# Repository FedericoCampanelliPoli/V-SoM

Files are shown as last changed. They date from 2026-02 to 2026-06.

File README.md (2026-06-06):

# V-SoM — Versatile System-on-Module for Power Electronics Debug & Control

<p align="center">
  
  &nbsp;&nbsp;
  
</p>

<p align="center">
  
  
  
  
  
</p>

<p align="center">
  <b>Develop. Deploy. Debug. Scale.</b><br/>
  A compact, production-ready embedded control module for power electronics, motor drives and custom control applications.
</p>

---

## Overview

Developing a custom power electronics controller typically requires:

- Designing dedicated control hardware from scratch
- Implementing communication interfaces and telemetry
- Integrating simulation environments with embedded targets
- Building software infrastructure before writing a single line of control code

**V-SoM eliminates this overhead.**

Built around the **STM32H755 dual-core microcontroller**, V-SoM combines high-performance real-time control, rapid prototyping workflows and integrated data acquisition into a single embeddable module — letting engineers focus on converter design and control algorithms rather than controller infrastructure.

---

## Key Features

| Feature | Specification |
|---|---|
| **MCU** | STM32H755 — Dual Core (Cortex-M7 + Cortex-M4) |
| **Control Core** | Cortex-M4 @ 240 MHz |
| **Communication Core** | Cortex-M7 |
| **PWM Outputs** | 5× HRTIM + 3× Advanced Timer complementary channels |
| **ADCs** | 3× 16-bit, up to 3.6 MSPS |
| **Analog Inputs** | 14 |
| **Ethernet** | 100 Mbps (integrated PHY + RJ45 with magnetics) |
| **Other Interfaces** | CAN, SPI, I²C |
| **GPIO** | 56 configurable pins |
| **Data Streaming** | Up to 60 channels @ 50 kSPS |
| **Form Factor** | 45 mm × 52 mm, 6-layer PCB, castellated edges |
| **Supply Voltage** | 3.3 V – 5.5 V |

---

## Architecture

V-SoM Architecture

| Core | Role |
|---|---|
| **Cortex-M7** | Ethernet communication, VScope server, variable read/write |
| **Cortex-M4** | User control algorithm, ADC sampling, PWM generation — fully dedicated |

This architecture guarantees **deterministic real-time execution** on the M4 while the M7 handles all telemetry and configuration transparently over Ethernet.

---

## VScope 2.0 — Integrated Real-Time Oscilloscope

One of the key features of V-SoM is **VScope 2.0**, an integrated virtual oscilloscope for real-time monitoring, editing and logging of variables running directly on the target.

<!-- ![VScope](images/vscope_main.png) -->

### Capabilities

| Capability | Detail |
|---|---|
| Channels | Up to **60** simultaneous |
| Sample Rate | Up to **50 kSPS** streaming |
| Live Editing | Modify variables at runtime |
| Acquisition | Oscilloscope-style triggering |
| Export | CSV |
| Post-processing | Supported |

Observable signals include measured variables, internal controller states, setpoints, duty cycles, protection thresholds and diagnostic data — without affecting real-time execution performance.

Communication runs over Ethernet, enabling **remote monitoring and debugging** with no additional instrumentation.

<!-- ![VScope Example](images/vscope_sinewave.png) -->
<!-- *Three-phase sinusoidal waveform streamed in real time to VScope.* -->

---

## Development Workflow

<!-- ![Workflow](images/workflow.png) -->

### 1 · Design

Develop and validate your controller in simulation:

- [PLECS](https://www.plexim.com/)
- [Simulink](https://www.mathworks.com/products/simulink.html) / Simscape
- Custom C

### 2 · Deploy

Generate embedded code or write firmware directly, then flash the target:

```bash
# Example: drag-and-drop via ST-Link (Cortex-M7 communication firmware)
# User control code runs on Cortex-M4 via your preferred toolchain
```

**Supported environments:**

| Toolchain | Target Core |
|---|---|
| Simulink Embedded Coder | Cortex-M4 |
| PLECS Coder | Cortex-M4 |
| STM32CubeIDE | Both |
| VS Code | Both |
| Bare-metal C | Both |

### 3 · Validate

Monitor all signals live with VScope 2.0 over Ethernet. Edit setpoints and parameters at runtime without stopping execution.

### 4 · Scale

Migrate the validated algorithm to a target production platform:

- STM32F4 / STM32G4 / STM32L4

or continue using V-SoM directly in **low and medium volume products**.

---

## Hardware

<!-- ![PCB Front & Back](images/vsom_front_back.png) -->
<!-- ![Pinout](images/vsom_pinout.png) -->

### Module

- **PCB:** 6-layer, 45 mm × 52 mm footprint
- **Connections:** Castellated edges — direct soldering onto carrier boards
- **Programmer:** STDC14 connector (ST-Link compatible, drag-and-drop firmware update)
- **Ethernet:** Integrated PHY + RJ45 with built-in magnetics

### Power Supply

- Dual low-noise LDO regulators
- Generates 3.3 V rail, up to **1 A** output
- Supply input: **3.3 V – 5.5 V**

### Galvanic Isolation

The integrated RJ45 connector includes built-in magnetics, providing galvanic isolation between the host PC, converter controller and external equipment — reducing EMI coupling and ground-loop issues in high-voltage environments.

---

## Applications

V-SoM has been designed for:

- Grid-tied inverters
- Motor drives (BLDC, PMSM, induction)
- Battery chargers and BMS
- Fuel-cell power converters
- Aerospace power systems
- High-voltage DC-DC converters
- Custom embedded control applications

---

## Default Firmware

The Cortex-M7 ships with communication firmware providing:

- **20 channels** read/write
- **20 kSPS** streaming rate
- Ethernet communication
- Full VScope 2.0 compatibility

Custom firmware can be flashed at any time via ST-Link drag-and-drop.

---

## Open Development Philosophy

V-SoM supports both **model-based design** (Simulink, PLECS) and **fully manual embedded development**. Engineers choose the environment that best fits their workflow while retaining full access to all underlying hardware resources.

No proprietary runtime. No closed ecosystem.

---

## Getting Started

> **Documentation:** [Insert link]  
> **Quick Start Guide:** [Insert link]

---

## Firewall Configuration

> [!WARNING]
> Windows Firewall may block incoming UDP packets required by VScope.

Run the following command **once** with administrator privileges:

```bash
netsh advfirewall firewall add rule name="VScope UDP 5005" dir=in action=allow protocol=UDP localport=5005
```

---

## License

[Insert License]

---

## Support

[Insert contact / issue tracker link]

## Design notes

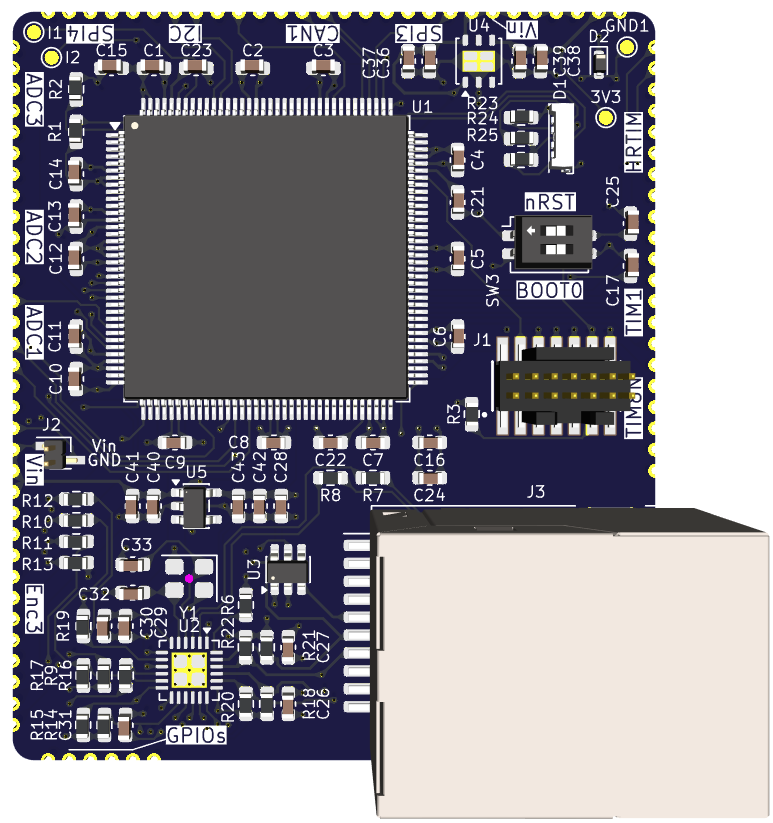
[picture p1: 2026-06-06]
Images/V-SoM_Rendering1.png

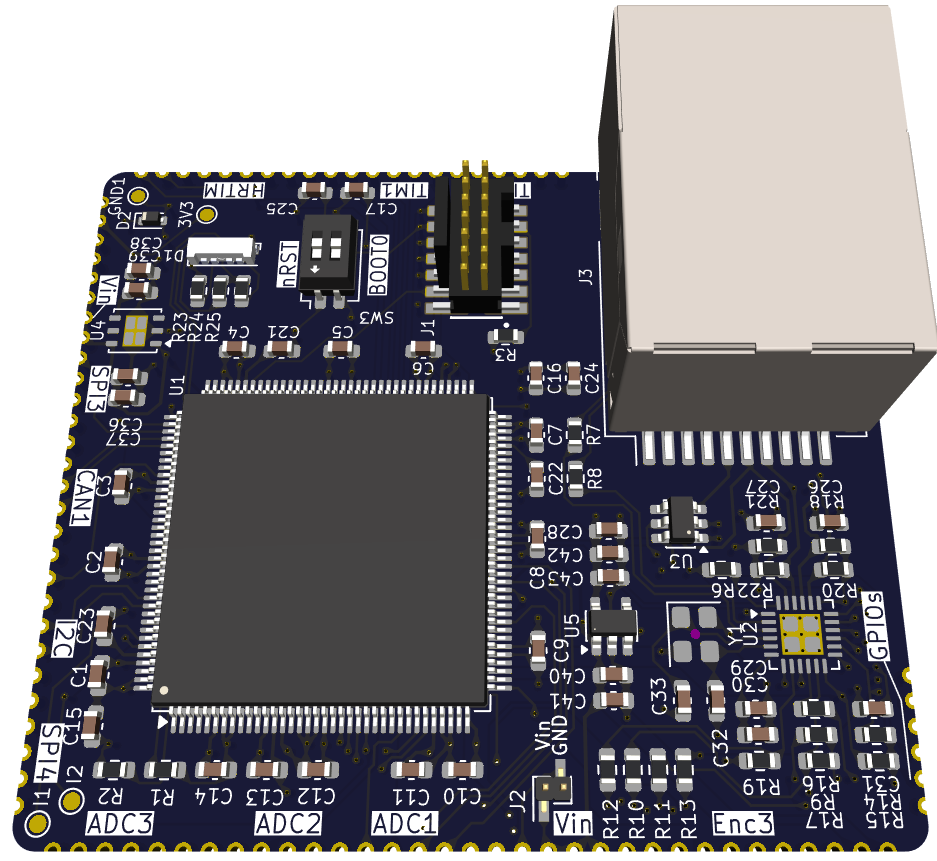
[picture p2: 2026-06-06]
Images/V-SoM_Rendering.png

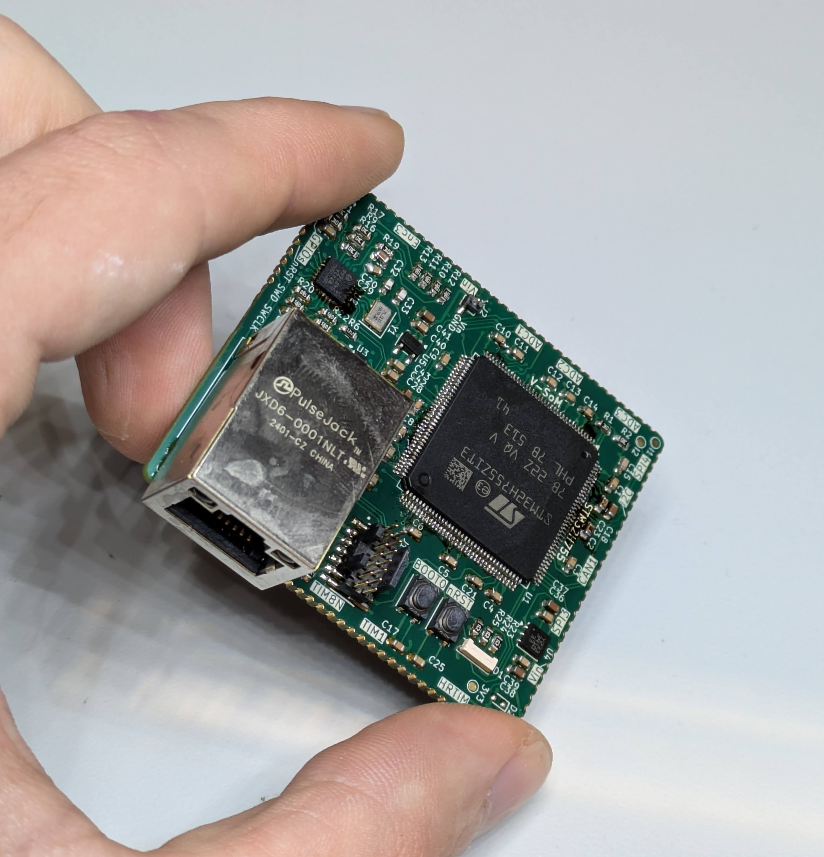
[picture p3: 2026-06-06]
Images/V-SoM_V1_Hand.jpg

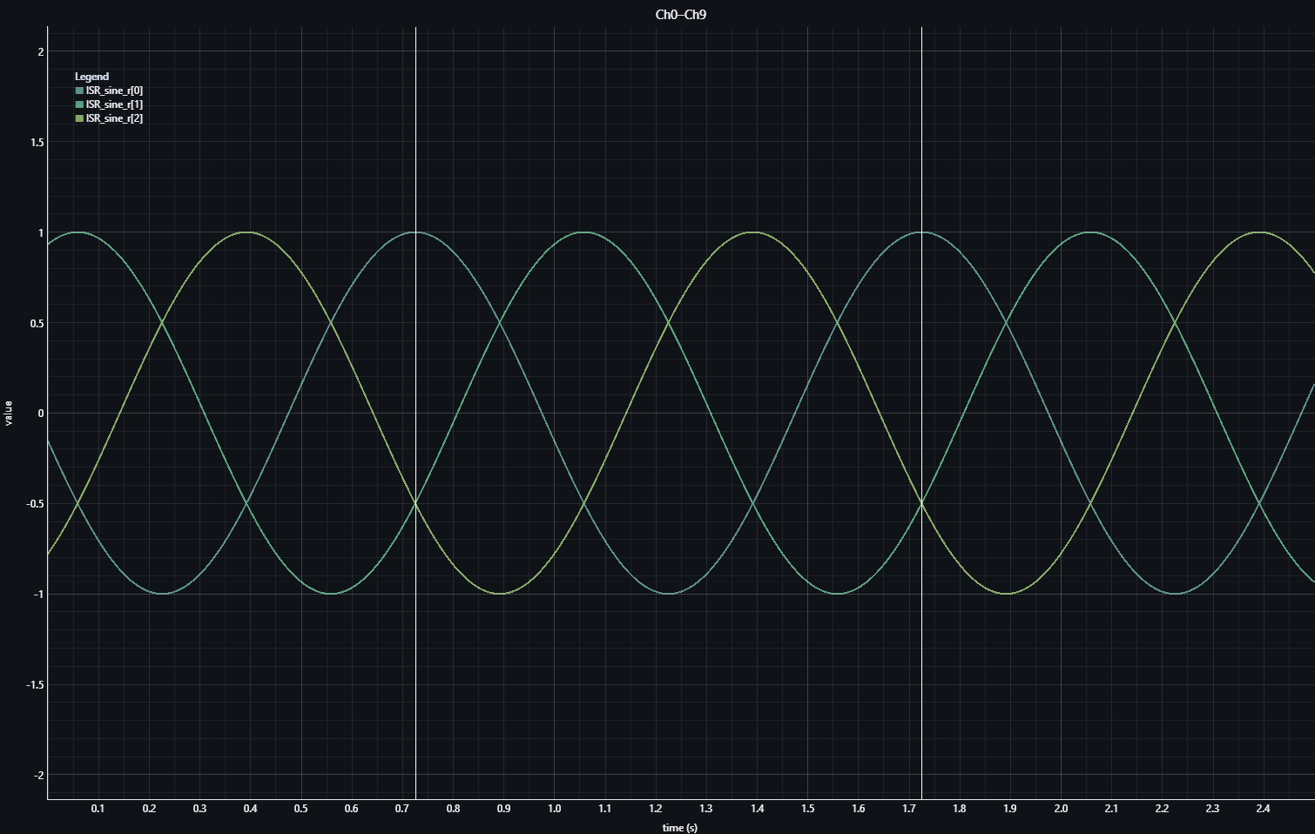
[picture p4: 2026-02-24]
Code/Images/VScope_0000.png

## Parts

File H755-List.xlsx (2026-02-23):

Il paese di origine potrebbe essere diverso al momento della spedizione.
Le informazioni HTSUS e ECCN visualizzate hanno solo scopo informativo e non rappresentano o garantiscono l'accuratezza o l'affidabilità di queste classificazioni. Tutte le informazioni vengono fornite &quot;viste e piaciute&quot; e sono soggette a modifiche senza preavviso. L'utilizzo delle informazioni fornite esenta Digi-Key da qualsiasi ricorso e l'utente si assume ogni rischio.
Indice | Codice produttore | Nome del produttore | Descrizione | Tempi di consegna | Disponibilità | Stato di magazzino | % di perdita | Quantità richiesta 1 | Quantità conf. 1 | Tipo conf. 1 | Codice Digi-Key 1 | Prezzo unitario 1 | Prezzo totale 1 | Quantità di ordinazione minima 1 | Riferimento cliente | Codice componente richiesto | Settimane di consegna | Scheda tecnica | Designazione riferimento | Tariffa di importazione USA | Nota | Stato componente | Stato RoHS | Stato REACH | Livello di sensibilità all'umidità (MSL) | ECCN | HTSUS | Paese di origine | Informazioni ambientali | Codici componente originali | Unità di misura | Immagine | Note di prodotto
1 | 1N4148WT | onsemi | DIODE STANDARD 75V 200MA SOD523F |  | 134.257 | In magazzino |  | 1 | 1 | Cut Tape (CT) | 1N4148WTCT-ND | 0,11000 | 0,11 $ | 1 |  | 1N4148WTCT-ND | 20 | https://mm.digikey.com/Volume0/opasdata/d220001/medias/docus/6621/1N914BWTCND.pdf |  | N/A |  | Attivo | A norma ROHS3 | Non interessato da REACH | 1 (illimitato) | EAR99 | 8541.10.0070 | China | https://www.onsemi.com/site/pdf/RoHS-statement.pdf|https://www.onsemi.com/site/pdf/REACH-compliance-statement.pdf|https://www.onsemi.com/PowerSolutions/MaterialComposition.do?export=pdf&opnId=1N4148WT | 1N4148WTCT-ND | EACH | https://mm.digikey.com/Volume0/opasdata/d220001/medias/images/6348/488%7EMKT-SOD523F1%7EW%7E2.jpg
2 | STDCQR1-25M | NDK (NIHON DEMPA KOGYO CO., LTD) | CRYSTAL 25.0000MHZ 8PF SMD |  | 33.016 | In magazzino |  | 1 | 1 | Cut Tape (CT) | 644-STDCQR1-25MCT-ND | 0,96000 | 0,96 $ | 1 |  | 644-STDCQR1-25MCT-ND | 15 | https://www.ndk.com/en/products/upload/lineup/pdf/NDKX03-00010_en.pdf |  | N/A |  | Attivo | A norma RoHS |  | 1 (illimitato) | EAR99 | 8541.60.0060 | Malaysia |  | 644-STDCQR1-25MCT-ND | EACH | https://mm.digikey.com/Volume0/opasdata/d220001/medias/images/59/NX3225SA%7E4-SMD%2CNO-LEAD%7E3%2C2x2%2C5_bottom.JPG
3 | NCP163ASN330T1G | onsemi | IC REG LINEAR 3.3V 250MA SOT23-5 |  | 26.679 | In magazzino |  | 1 | 1 | Cut Tape (CT) | NCP163ASN330T1GOSCT-ND | 0,38000 | 0,38 $ | 1 |  | NCP163ASN330T1GOSCT-ND | 13 | https://www.onsemi.com/pdf/datasheet/ncp163-d.pdf |  | N/A |  | Attivo | A norma ROHS3 | Non interessato da REACH | 1 (illimitato) | EAR99 | 8542.39.0090 | Thailand | https://www.onsemi.com/site/pdf/RoHS-statement.pdf | NCP163ASN330T1GOSCT-ND | EACH | https://mm.digikey.com/Volume0/opasdata/d220001/medias/images/2614/488%7E527AH%7E%7E5.JPG
4 | LD39100PU33R | STMicroelectronics | IC REG LINEAR 3.3V 1A 6-DFN |  | 4.959 | In magazzino |  | 1 | 1 | Cut Tape (CT) | 497-17047-1-ND | 1,12000 | 1,12 $ | 1 |  | 497-17047-1-ND | 24 | https://www.st.com/content/ccc/resource/technical/document/datasheet/72/02/e5/ee/df/36/40/5e/CD00233788.pdf/files/CD00233788.pdf/jcr:content/translations/en.C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 |  | N/A |  | Attivo | A norma ROHS3 | Non interessato da REACH | 1 (illimitato) | EAR99 | 8542.39.0090 | Malaysia |  | 497-17047-1-ND | EACH | https://mm.digikey.com/Volume0/opasdata/d220001/medias/images/6253/497%7E7946637%7E%7E6.jpg
5 | USBLC6-4SC6 | STMicroelectronics | TVS DIODE 5.25VWM 17VC SOT23-6 |  | 175.677 | In magazzino |  | 1 | 1 | Cut Tape (CT) | 497-4492-1-ND | 0,35000 | 0,35 $ | 1 |  | 497-4492-1-ND | 25 | https://www.st.com/resource/en/datasheet/cd00047494.pdf |  | N/A |  | Attivo | A norma ROHS3 | Non interessato da REACH | 1 (illimitato) | EAR99 | 8541.10.0080 | Singapore |  | 497-4492-1-ND | EACH | https://mm.digikey.com/Volume0/opasdata/d220001/medias/images/2605/SOT-23-6%20PKG.jpg
6 | LAN8742A-CZ | Microchip Technology | IC TRANSCEIVER 1/1 24SQFN |  | 2.376 | In magazzino |  | 1 | 1 | Tray | LAN8742A-CZ-ND | 1,53000 | 1,53 $ | 1 |  | LAN8742A-CZ-ND | 6 | https://ww1.microchip.com/downloads/en/DeviceDoc/DS_LAN8742_00001989A.pdf |  | N/A |  | Attivo | A norma ROHS3 | Non interessato da REACH | 3 (168 ore) | 5A991B1 | 8542.39.0070 | Taiwan | https://ww1.microchip.com/downloads/aemDocuments/documents/corporate-responsibilty/environmental/product-regulatory-information/Semiconductor_EnvCoC.pdf|https://ww1.microchip.com/downloads/aemDocuments/documents/corporate-responsibilty/environmental/product-regulatory-information/Microchip_REACH_Statement.pdf | LAN8742A-CZ-ND | EACH | https://mm.digikey.com/Volume0/opasdata/d220001/medias/images/4849/150_24-VFQFN%20Exposed%20Pad.jpg
7 | STM32H755ZIT6 | STMicroelectronics | IC MCU 32BIT 2MB FLASH 144LQFP |  | 876 | In magazzino |  | 1 | 1 | Tray | STM32H755ZIT6-ND | 18,26000 | 18,26 $ | 1 |  | STM32H755ZIT6-ND | 15 | https://www.st.com/resource/en/datasheet/stm32h755bi.pdf |  | N/A |  | Attivo | A norma ROHS3 | Non interessato da REACH | 3 (168 ore) | 5A992C | 8542.31.0025 | France |  | STM32H755ZIT6-ND | EACH | https://mm.digikey.com/Volume0/opasdata/d220001/medias/images/6311/497%7E144LQFP-1.6-20X20%7E%7E144.jpg
8 | RC0603FR-0756RL | YAGEO | RES 56 OHM 1% 1/10W 0603 |  | 179.420 | In magazzino |  | 10 | 10 | Cut Tape (CT) | 311-56.0HRCT-ND | 0,00600 | 0,06 $ | 1 |  | 311-56.0HRCT-ND | 18 | https://yageogroup.com/content/datasheet/asset/file/PYU-RC_GROUP_51_ROHS_L |  | N/A |  | Attivo | A norma ROHS3 | Non interessato da REACH | 1 (illimitato) | EAR99 | 8533.21.0030 | Taiwan | https://www.yageogroup.com/content/Resource%20Library/Product%20Environmental%20Compliance/RoHS_Compliance_YAGEO.pdf | 311-56.0HRCT-ND | EACH | https://mm.digikey.com/Volume0/opasdata/d220001/derivates/6/100/962/238/13_0603-%281608-metric%29_web%28640x640%29.jpg
9 | RMCF0603FT270R | Stackpole Electronics Inc | RES 270 OHM 1% 1/10W 0603 |  | 800.492 | In magazzino |  | 5 | 5 | Cut Tape (CT) | RMCF0603FT270RCT-ND | 0,10000 | 0,50 $ | 1 |  | RMCF0603FT270RCT-ND | 18 | https://www.seielect.com/catalog/SEI-RMCF_RMCP.pdf |  | N/A |  | Attivo | A norma ROHS3 | Non interessato da REACH | 1 (illimitato) | EAR99 | 8533.21.0030 | Taiwan | https://www.seielect.com/catalog/SEI-RoHS_Compliance_Status.pdf|https://www.seielect.com/catalog/reach.pdf|https://www.seielect.com/catalog/sei-coc%20prop%2065.pdf | RMCF0603FT270RCT-ND | EACH | https://mm.digikey.com/Volume0/opasdata/d220001/medias/images/4849/738_0603.jpg
10 | CRCW060312K1FKEAC | Vishay Dale | RES 12.1K OHM 1% 1/10W 0603 |  | 482.032 | In magazzino |  | 1 | 1 | Cut Tape (CT) | 541-5158-1-ND | 0,10000 | 0,10 $ | 1 |  | 541-5158-1-ND | 16 | https://www.vishay.com/docs/28773/crcwce3.pdf |  | N/A |  | Attivo | A norma ROHS3 | Non interessato da REACH | 1 (illimitato) | EAR99 | 8533.21.0030 | China |  | 541-5158-1-ND | EACH | https://mm.digikey.com/Volume0/opasdata/d220001/medias/images/2491/CRCW%200603%20%281608metric%29.jpg
11 | RC0603FR-0710KL | YAGEO | RES 10K OHM 1% 1/10W 0603 |  | 5.531.584 | In magazzino |  | 8 | 8 | Cut Tape (CT) | 311-10.0KHRCT-ND | 0,10000 | 0,80 $ | 1 |  | 311-10.0KHRCT-ND | 18 | https://yageogroup.com/content/datasheet/asset/file/PYU-RC_GROUP_51_ROHS_L |  | N/A |  | Attivo | A norma ROHS3 | Non interessato da REACH | 1 (illimitato) | EAR99 | 8533.21.0030 | Taiwan | https://www.yageogroup.com/content/Resource%20Library/Product%20Environmental%20Compliance/RoHS_Compliance_YAGEO.pdf | 311-10.0KHRCT-ND | EACH | https://mm.digikey.com/Volume0/opasdata/d220001/medias/images/4322/cut-tape-render.jpg
12 | JXD6-0001NLT | Pulse Electronics | CONN JACK 1PORT SURFACE MOUNT |  | 369 | In magazzino |  | 1 | 1 | Cut Tape (CT) | 553-JXD6-0001NLTCT-ND | 4,65000 | 4,65 $ | 1 |  | 553-JXD6-0001NLTCT-ND | 8 | https://productfinder.pulseelectronics.com/api/open/part-attachments/datasheet/JXD6-0001NLT |  | N/A |  | Attivo | A norma ROHS3 | Non interessato da REACH | 1 (illimitato) | EAR99 | 8536.69.4040 | China |  | 553-JXD6-0001NLTCT-ND | EACH | https://mm.digikey.com/Volume0/opasdata/d220001/medias/images/5751/MFG_JXD6-000xNLT.jpg
13 | BC032-02-A-2-0200-0200-L-B | GCT | 2POS 1.0MM PITCH PIN HEADER, TYP |  | 995 | In magazzino |  | 1 | 1 | Cut Tape (CT) | 2073-BC032-02-A-2-0200-0200-L-BCT-ND | 1,08000 | 1,08 $ | 1 |  | 2073-BC032-02-A-2-0200-0200-L-BCT-ND | 8 | https://gct.co/files/specs/1.00mm-header-spec.pdf |  | N/A |  | Attivo | A norma ROHS3 | Non interessato da REACH | 1 (illimitato) | EAR99 | 8536.69.4040 | China | https://gct.co/files/info/gct_certificate_of_compliance.pdf | 2073-BC032-02-A-2-0200-0200-L-BCT-ND | EACH | https://mm.digikey.com/Volume0/opasdata/d220001/medias/images/435/MFG_BC032-02-A-02-0200-0200-L-B.jpg
14 | FTSH-107-01-L-DV-K | Samtec Inc. | CONN HEADER SMD 14POS 1.27MM |  | 13.344 | In magazzino |  | 1 | 1 | Tube | SAM9449-ND | 3,77000 | 3,77 $ | 1 |  | SAM9449-ND | 4 | https://suddendocs.samtec.com/catalog_english/ftsh_smt.pdf |  | N/A |  | Attivo | A norma ROHS3 | Non interessato da REACH | 1 (illimitato) | EAR99 | 8536.69.4040 | Malaysia |  | SAM9449-ND | EACH | https://mm.digikey.com/Volume0/opasdata/d220001/derivates/6/008/131/269/MFG_INC743-FTSH-107-0x-x-DV-K-28P29_web%28640x640%29.jpg
15 | QLS6B-FKW-CNSNSF043 | Cree LED | LED RGB 6PLCC SMD R/A |  | 64.307 | In magazzino |  | 1 | 1 | Cut Tape (CT) | QLS6B-FKW-CNSNSF043CT-ND | 0,43000 | 0,43 $ | 1 |  | QLS6B-FKW-CNSNSF043CT-ND | 2 | https://downloads.cree-led.com/files/ds/h/HB-QLS6B-FKW.pdf |  | N/A |  | Attivo | A norma ROHS3 | Non interessato da REACH | 3 (168 ore) | EAR99 | 8541.41.0000 | China |  | QLS6B-FKW-CNSNSF043CT-ND | EACH | https://mm.digikey.com/Volume0/opasdata/d220001/medias/images/4837/QLS6B-FKW-CNSNSF043.jpg
16 | C0603C569C5GACTU | KEMET | CAP CER 5.6PF 50V C0G/NP0 0603 |  | 27.098 | In magazzino |  | 2 | 2 | Cut Tape (CT) | 399-C0603C569C5GACTUCT-ND | 0,10000 | 0,20 $ | 1 |  | 399-C0603C569C5GACTUCT-ND | 13 | https://yageogroup.com/content/datasheet/asset/file/KEM_C1003_C0G_SMD |  | N/A |  | Attivo | A norma ROHS3 | Non interessato da REACH | 1 (illimitato) | EAR99 | 8532.24.0020 | Mexico |  | 399-C0603C569C5GACTUCT-ND | EACH | https://mm.digikey.com/Volume0/opasdata/d220001/medias/images/5352/0603-%281608-Metric%29-Ceramic-Capacitor.jpg
17 | C0603C471K5RACTU | KEMET | CAP CER 470PF 50V X7R 0603 |  | 40.510 | In magazzino |  | 1 | 1 | Cut Tape (CT) | 399-C0603C471K5RACTUCT-ND | 0,10000 | 0,10 $ | 1 |  | 399-C0603C471K5RACTUCT-ND | 13 | https://yageogroup.com/content/datasheet/asset/file/KEM_C1002_X7R_SMD |  | N/A |  | Attivo | A norma ROHS3 | Non interessato da REACH | 1 (illimitato) | EAR99 | 8532.24.0020 | Mexico |  | 399-C0603C471K5RACTUCT-ND | EACH | https://mm.digikey.com/Volume0/opasdata/d220001/medias/images/4322/cut-tape-render.jpg
18 | GRM188R61E475KE11D | Murata Electronics | CAP CER 4.7UF 25V X5R 0603 |  | 241.432 | In magazzino |  | 8 | 8 | Cut Tape (CT) | 490-7203-1-ND | 0,08000 | 0,64 $ | 1 |  | 490-7203-1-ND | 12 | https://search.murata.co.jp/Ceramy/image/img/A01X/G101/ENG/GRM188R61E475KE11-01.pdf |  | N/A |  | Attivo | A norma ROHS3 | Non interessato da REACH | 1 (illimitato) | EAR99 | 8532.24.0020 | Japan |  | 490-7203-1-ND | EACH | https://mm.digikey.com/Volume0/opasdata/d220001/medias/images/4322/cut-tape-render.jpg
19 | C0603C104K5RACTU | KEMET | CAP CER 0.1UF 50V X7R 0603 |  | 12.223.983 | In magazzino |  | 29 | 29 | Cut Tape (CT) | 399-C0603C104K5RACTUCT-ND | 0,01100 | 0,32 $ | 1 |  | 399-C0603C104K5RACTUCT-ND | 11 | https://yageogroup.com/content/datasheet/asset/file/KEM_C1002_X7R_SMD |  | N/A |  | Attivo | A norma ROHS3 | Non interessato da REACH | 1 (illimitato) | EAR99 | 8532.24.0020 | China |  | 399-C0603C104K5RACTUCT-ND | EACH | https://mm.digikey.com/Volume0/opasdata/d220001/medias/images/4322/cut-tape-render.jpg

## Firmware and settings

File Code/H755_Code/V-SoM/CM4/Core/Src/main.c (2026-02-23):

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
/* Includes ------------------------------------------------------------------*/
#include "main.h"

/* USER CODE BEGIN PD */
#ifndef HSEM_ID_0
#define HSEM_ID_0 (0U) /* HW semaphore 0*/
#endif
/* USER CODE END PD */

ADC_HandleTypeDef hadc1;
DMA_HandleTypeDef hdma_adc1;

HRTIM_HandleTypeDef hhrtim;

TIM_HandleTypeDef htim1;

static void MX_DMA_Init(void);
static void MX_TIM1_Init(void);
static void MX_HRTIM_Init(void);
static void MX_ADC1_Init(void);
/**
  * @brief  The application entry point.
  * @retval int
  */
int main(void)
{

/* USER CODE BEGIN Boot_Mode_Sequence_1 */
	/* ETH_CODE: fixed core synchronization
	 * Busy wait, since entering STOP mode breaks debug session.
	 */
	__HAL_RCC_HSEM_CLK_ENABLE();
	while((__HAL_HSEM_GET_FLAG(__HAL_HSEM_SEMID_TO_MASK(HSEM_ID_0))) == 0);
	__HAL_HSEM_CLEAR_FLAG(__HAL_HSEM_SEMID_TO_MASK(HSEM_ID_0));
/* USER CODE END Boot_Mode_Sequence_1 */
  /* MCU Configuration--------------------------------------------------------*/

  /* Reset of all peripherals, Initializes the Flash interface and the Systick. */
  HAL_Init();

  /* Initialize all configured peripherals */
  MX_GPIO_Init();
  MX_DMA_Init();
  MX_TIM1_Init();
  MX_HRTIM_Init();
  MX_ADC1_Init();
  /* USER CODE BEGIN 2 */

//  VScope.buffer[0]=&;
  VScope.buffer[1]=&ISR_frequency;
  VScope.buffer[2]=&ISR_M_d;
  VScope.buffer[3]=&ISR_sine_r[0];
  VScope.buffer[4]=&ISR_sine_r[1];
  VScope.buffer[5]=&ISR_sine_r[2];
  VScope.buffer[6]=&ADC1_RC_r;
  VScope.buffer[7]=&ADC1_JC_r[0];
  VScope.buffer[8]=&ADC1_JC_r[1];

  SET_BIT(TIM1->CR1,  TIM_CR1_CEN);
  SET_BIT(TIM1->DIER, TIM_DIER_UIE);
  SET_BIT(TIM1->CCER, TIM_CCER_CC1E | TIM_CCER_CC1NE);
  SET_BIT(TIM1->BDTR, TIM_BDTR_MOE);

  WRITE_REG(TIM1->RCR,1);

  MODIFY_REG(HRTIM1->sMasterRegs.MCR, 0b111, 0b011);
  MODIFY_REG(HRTIM1->sTimerxRegs[0].TIMxCR, 0b111, 0b011);

  SET_BIT(HRTIM1->sMasterRegs.MCR, HRTIM_MCR_MCEN);

  SET_BIT(HRTIM1->sMasterRegs.MCR, HRTIM_MCR_TACEN);
  SET_BIT(HRTIM1->sCommonRegs.OENR, HRTIM_OENR_TA1OEN | HRTIM_OENR_TA2OEN);

  SET_BIT(HSEM->C2IER,__HAL_HSEM_SEMID_TO_MASK(1));

  HAL_ADC_Start_DMA(&hadc1, (uint32_t*)&ADC1_RC, 1);
  SET_BIT(ADC1->CR, ADC_CR_JADSTART);
  /* USER CODE END 2 */

  /* Infinite loop */
  /* USER CODE BEGIN WHILE */
  while (1)
  {
    /* USER CODE END WHILE */

    /* USER CODE BEGIN 3 */
  }
  /* USER CODE END 3 */
}

/**
  * @brief ADC1 Initialization Function
  * @param None
  * @retval None
  */
static void MX_ADC1_Init(void)
{

  ADC_MultiModeTypeDef multimode = {0};
  ADC_ChannelConfTypeDef sConfig = {0};
  ADC_InjectionConfTypeDef sConfigInjected = {0};

  /** Common config
  */
  hadc1.Instance = ADC1;
  hadc1.Init.ClockPrescaler = ADC_CLOCK_ASYNC_DIV4;
  hadc1.Init.Resolution = ADC_RESOLUTION_16B;
  hadc1.Init.ScanConvMode = ADC_SCAN_ENABLE;
  hadc1.Init.EOCSelection = ADC_EOC_SINGLE_CONV;
  hadc1.Init.LowPowerAutoWait = DISABLE;
  hadc1.Init.ContinuousConvMode = ENABLE;
  hadc1.Init.NbrOfConversion = 1;
  hadc1.Init.DiscontinuousConvMode = DISABLE;
  hadc1.Init.ExternalTrigConv = ADC_SOFTWARE_START;
  hadc1.Init.ExternalTrigConvEdge = ADC_EXTERNALTRIGCONVEDGE_NONE;
  hadc1.Init.ConversionDataManagement = ADC_CONVERSIONDATA_DMA_CIRCULAR;
  hadc1.Init.Overrun = ADC_OVR_DATA_PRESERVED;
  hadc1.Init.LeftBitShift = ADC_LEFTBITSHIFT_NONE;
  hadc1.Init.OversamplingMode = ENABLE;
  hadc1.Init.Oversampling.Ratio = 10;
  hadc1.Init.Oversampling.RightBitShift = ADC_RIGHTBITSHIFT_NONE;
  hadc1.Init.Oversampling.TriggeredMode = ADC_TRIGGEREDMODE_SINGLE_TRIGGER;
  hadc1.Init.Oversampling.OversamplingStopReset = ADC_REGOVERSAMPLING_CONTINUED_MODE;
  if (HAL_ADC_Init(&hadc1) != HAL_OK)
  {
    Error_Handler();
  }

  /** Configure the ADC multi-mode
  */
  multimode.Mode = ADC_MODE_INDEPENDENT;
  if (HAL_ADCEx_MultiModeConfigChannel(&hadc1, &multimode) != HAL_OK)
  {
    Error_Handler();
  }

  /** Disable Injected Queue
  */
  HAL_ADCEx_DisableInjectedQueue(&hadc1);

  /** Configure Regular Channel
  */
  sConfig.Channel = ADC_CHANNEL_2;
  sConfig.Rank = ADC_REGULAR_RANK_1;
  sConfig.SamplingTime = ADC_SAMPLETIME_8CYCLES_5;
  sConfig.SingleDiff = ADC_SINGLE_ENDED;
  sConfig.OffsetNumber = ADC_OFFSET_NONE;
  sConfig.Offset = 0;
  sConfig.OffsetSignedSaturation = DISABLE;
  if (HAL_ADC_ConfigChannel(&hadc1, &sConfig) != HAL_OK)
  {
    Error_Handler();
  }

  /** Configure Injected Channel
  */
  sConfigInjected.InjectedChannel = ADC_CHANNEL_2;
  sConfigInjected.InjectedRank = ADC_INJECTED_RANK_1;
  sConfigInjected.InjectedSamplingTime = ADC_SAMPLETIME_8CYCLES_5;
  sConfigInjected.InjectedSingleDiff = ADC_SINGLE_ENDED;
  sConfigInjected.InjectedOffsetNumber = ADC_OFFSET_NONE;
  sConfigInjected.InjectedOffset = 0;
  sConfigInjected.InjectedOffsetSignedSaturation = DISABLE;
  sConfigInjected.InjectedNbrOfConversion = 2;
  sConfigInjected.InjectedDiscontinuousConvMode = DISABLE;
  sConfigInjected.AutoInjectedConv = DISABLE;
  sConfigInjected.QueueInjectedContext = DISABLE;
  sConfigInjected.ExternalTrigInjecConv = ADC_EXTERNALTRIGINJEC_T1_TRGO;
  sConfigInjected.ExternalTrigInjecConvEdge = ADC_EXTERNALTRIGINJECCONV_EDGE_RISING;
  sConfigInjected.InjecOversamplingMode = DISABLE;
  if (HAL_ADCEx_InjectedConfigChannel(&hadc1, &sConfigInjected) != HAL_OK)
  {
    Error_Handler();
  }

  /** Configure Injected Channel
  */
  sConfigInjected.InjectedChannel = ADC_CHANNEL_5;
  sConfigInjected.InjectedRank = ADC_INJECTED_RANK_2;
  if (HAL_ADCEx_InjectedConfigChannel(&hadc1, &sConfigInjected) != HAL_OK)
  {
    Error_Handler();
  }
}

/**
  * @brief HRTIM Initialization Function
  * @param None
  * @retval None
  */
static void MX_HRTIM_Init(void)
{

  HRTIM_TimeBaseCfgTypeDef pTimeBaseCfg = {0};
  HRTIM_TimerCfgTypeDef pTimerCfg = {0};
  HRTIM_CompareCfgTypeDef pCompareCfg = {0};
  HRTIM_DeadTimeCfgTypeDef pDeadTimeCfg = {0};
  HRTIM_OutputCfgTypeDef pOutputCfg = {0};

  hhrtim.Instance = HRTIM1;
  hhrtim.Init.HRTIMInterruptResquests = HRTIM_IT_NONE;
  hhrtim.Init.SyncOptions = HRTIM_SYNCOPTION_SLAVE;
  hhrtim.Init.SyncInputSource = HRTIM_SYNCINPUTSOURCE_INTERNALEVENT;
  if (HAL_HRTIM_Init(&hhrtim) != HAL_OK)
  {
    Error_Handler();
  }
  pTimeBaseCfg.Period = ARR;
  pTimeBaseCfg.RepetitionCounter = 0x00;
  pTimeBaseCfg.PrescalerRatio = HRTIM_PRESCALERRATIO_DIV1;
  pTimeBaseCfg.Mode = HRTIM_MODE_SINGLESHOT_RETRIGGERABLE;
  if (HAL_HRTIM_TimeBaseConfig(&hhrtim, HRTIM_TIMERINDEX_MASTER, &pTimeBaseCfg) != HAL_OK)
  {
    Error_Handler();
  }
  pTimerCfg.InterruptRequests = HRTIM_MASTER_IT_MREP;
  pTimerCfg.DMARequests = HRTIM_MASTER_DMA_NONE;
  pTimerCfg.DMASrcAddress = 0x0000;
  pTimerCfg.DMADstAddress = 0x0000;
  pTimerCfg.DMASize = 0x1;
  pTimerCfg.HalfModeEnable = HRTIM_HALFMODE_DISABLED;
  pTimerCfg.StartOnSync = HRTIM_SYNCSTART_DISABLED;
  pTimerCfg.ResetOnSync = HRTIM_SYNCRESET_ENABLED;
  pTimerCfg.DACSynchro = HRTIM_DACSYNC_NONE;
  pTimerCfg.PreloadEnable = HRTIM_PRELOAD_DISABLED;
  pTimerCfg.UpdateGating = HRTIM_UPDATEGATING_INDEPENDENT;
  pTimerCfg.BurstMode = HRTIM_TIMERBURSTMODE_MAINTAINCLOCK;
  pTimerCfg.RepetitionUpdate = HRTIM_UPDATEONREPETITION_ENABLED;
  if (HAL_HRTIM_WaveformTimerConfig(&hhrtim, HRTIM_TIMERINDEX_MASTER, &pTimerCfg) != HAL_OK)
  {
    Error_Handler();
  }
  pCompareCfg.CompareValue = ARR/2;
  if (HAL_HRTIM_WaveformCompareConfig(&hhrtim, HRTIM_TIMERINDEX_MASTER, HRTIM_COMPAREUNIT_1, &pCompareCfg) != HAL_OK)
  {
    Error_Handler();
  }
  pTimeBaseCfg.Mode = HRTIM_MODE_CONTINUOUS;
  if (HAL_HRTIM_TimeBaseConfig(&hhrtim, HRTIM_TIMERINDEX_TIMER_A, &pTimeBaseCfg) != HAL_OK)
  {
    Error_Handler();
  }
  pTimerCfg.InterruptRequests = HRTIM_TIM_IT_NONE;
  pTimerCfg.DMARequests = HRTIM_TIM_DMA_NONE;
  pTimerCfg.ResetOnSync = HRTIM_SYNCRESET_DISABLED;
  pTimerCfg.PreloadEnable = HRTIM_PRELOAD_ENABLED;
  pTimerCfg.PushPull = HRTIM_TIMPUSHPULLMODE_DISABLED;
  pTimerCfg.FaultEnable = HRTIM_TIMFAULTENABLE_NONE;
  pTimerCfg.FaultLock = HRTIM_TIMFAULTLOCK_READWRITE;
  pTimerCfg.DeadTimeInsertion = HRTIM_TIMDEADTIMEINSERTION_ENABLED;
  pTimerCfg.DelayedProtectionMode = HRTIM_TIMER_A_B_C_DELAYEDPROTECTION_DISABLED;
  pTimerCfg.UpdateTrigger = HRTIM_TIMUPDATETRIGGER_NONE;
  pTimerCfg.ResetTrigger = HRTIM_TIMRESETTRIGGER_MASTER_PER;
  pTimerCfg.ResetUpdate = HRTIM_TIMUPDATEONRESET_DISABLED;
  if (HAL_HRTIM_WaveformTimerConfig(&hhrtim, HRTIM_TIMERINDEX_TIMER_A, &pTimerCfg) != HAL_OK)
  {
    Error_Handler();
  }
  pCompareCfg.CompareValue = 0xFFFD;
  if (HAL_HRTIM_WaveformCompareConfig(&hhrtim, HRTIM_TIMERINDEX_TIMER_A, HRTIM_COMPAREUNIT_1, &pCompareCfg) != HAL_OK)
  {
    Error_Handler();
  }
  pCompareCfg.AutoDelayedMode = HRTIM_AUTODELAYEDMODE_REGULAR;
  pCompareCfg.AutoDelayedTimeout = 0x0000;

  if (HAL_HRTIM_WaveformCompareConfig(&hhrtim, HRTIM_TIMERINDEX_TIMER_A, HRTIM_COMPAREUNIT_2, &pCompareCfg) != HAL_OK)
  {
    Error_Handler();
  }
  pDeadTimeCfg.Prescaler = HRTIM_TIMDEADTIME_PRESCALERRATIO_DIV1;
  pDeadTimeCfg.RisingValue = 0x010;
  pDeadTimeCfg.RisingSign = HRTIM_TIMDEADTIME_RISINGSIGN_POSITIVE;
  pDeadTimeCfg.RisingLock = HRTIM_TIMDEADTIME_RISINGLOCK_WRITE;
  pDeadTimeCfg.RisingSignLock = HRTIM_TIMDEADTIME_RISINGSIGNLOCK_WRITE;
  pDeadTimeCfg.FallingValue = 0x010;
  pDeadTimeCfg.FallingSign = HRTIM_TIMDEADTIME_FALLINGSIGN_POSITIVE;
  pDeadTimeCfg.FallingLock = HRTIM_TIMDEADTIME_FALLINGLOCK_WRITE;
  pDeadTimeCfg.FallingSignLock = HRTIM_TIMDEADTIME_FALLINGSIGNLOCK_WRITE;
  if (HAL_HRTIM_DeadTimeConfig(&hhrtim, HRTIM_TIMERINDEX_TIMER_A, &pDeadTimeCfg) != HAL_OK)
  {
    Error_Handler();
  }
  pOutputCfg.Polarity = HRTIM_OUTPUTPOLARITY_HIGH;
  pOutputCfg.SetSource = HRTIM_OUTPUTSET_TIMCMP1;
  pOutputCfg.ResetSource = HRTIM_OUTPUTRESET_TIMCMP2;
  pOutputCfg.IdleMode = HRTIM_OUTPUTIDLEMODE_NONE;
  pOutputCfg.IdleLevel = HRTIM_OUTPUTIDLELEVEL_INACTIVE;
  pOutputCfg.FaultLevel = HRTIM_OUTPUTFAULTLEVEL_NONE;
  pOutputCfg.ChopperModeEnable = HRTIM_OUTPUTCHOPPERMODE_DISABLED;
  pOutputCfg.BurstModeEntryDelayed = HRTIM_OUTPUTBURSTMODEENTRY_REGULAR;
  if (HAL_HRTIM_WaveformOutputConfig(&hhrtim, HRTIM_TIMERINDEX_TIMER_A, HRTIM_OUTPUT_TA1, &pOutputCfg) != HAL_OK)
  {
    Error_Handler();
  }
  pOutputCfg.SetSource = HRTIM_OUTPUTSET_NONE;
  pOutputCfg.ResetSource = HRTIM_OUTPUTRESET_NONE;
  if (HAL_HRTIM_WaveformOutputConfig(&hhrtim, HRTIM_TIMERINDEX_TIMER_A, HRTIM_OUTPUT_TA2, &pOutputCfg) != HAL_OK)
  {
    Error_Handler();
  }
  HAL_HRTIM_MspPostInit(&hhrtim);

}

/**
  * @brief TIM1 Initialization Function
  * @param None
  * @retval None
  */
static void MX_TIM1_Init(void)
{

  TIM_ClockConfigTypeDef sClockSourceConfig = {0};
  TIM_MasterConfigTypeDef sMasterConfig = {0};
  TIM_OC_InitTypeDef sConfigOC = {0};
  TIM_BreakDeadTimeConfigTypeDef sBreakDeadTimeConfig = {0};

  htim1.Instance = TIM1;
  htim1.Init.Prescaler = 0;
  htim1.Init.CounterMode = TIM_COUNTERMODE_CENTERALIGNED3;
  htim1.Init.Period = 5000;
  htim1.Init.ClockDivision = TIM_CLOCKDIVISION_DIV1;
  htim1.Init.RepetitionCounter = 0;
  htim1.Init.AutoReloadPreload = TIM_AUTORELOAD_PRELOAD_DISABLE;
  if (HAL_TIM_Base_Init(&htim1) != HAL_OK)
  {
    Error_Handler();
  }
  sClockSourceConfig.ClockSource = TIM_CLOCKSOURCE_INTERNAL;
  if (HAL_TIM_ConfigClockSource(&htim1, &sClockSourceConfig) != HAL_OK)
  {
    Error_Handler();
  }
  if (HAL_TIM_PWM_Init(&htim1) != HAL_OK)
  {
    Error_Handler();
  }
  sMasterConfig.MasterOutputTrigger = TIM_TRGO_UPDATE;
  sMasterConfig.MasterOutputTrigger2 = TIM_TRGO2_RESET;
  sMasterConfig.MasterSlaveMode = TIM_MASTERSLAVEMODE_DISABLE;
  if (HAL_TIMEx_MasterConfigSynchronization(&htim1, &sMasterConfig) != HAL_OK)
  {
    Error_Handler();
  }
  sConfigOC.OCMode = TIM_OCMODE_PWM1;
  sConfigOC.Pulse = 0;
  sConfigOC.OCPolarity = TIM_OCPOLARITY_HIGH;
  sConfigOC.OCNPolarity = TIM_OCNPOLARITY_HIGH;
  sConfigOC.OCFastMode = TIM_OCFAST_DISABLE;
  sConfigOC.OCIdleState = TIM_OCIDLESTATE_RESET;
  sConfigOC.OCNIdleState = TIM_OCNIDLESTATE_RESET;
  if (HAL_TIM_PWM_ConfigChannel(&htim1, &sConfigOC, TIM_CHANNEL_1) != HAL_OK)
  {
    Error_Handler();
  }
  sBreakDeadTimeConfig.OffStateRunMode = TIM_OSSR_DISABLE;
  sBreakDeadTimeConfig.OffStateIDLEMode = TIM_OSSI_DISABLE;
  sBreakDeadTimeConfig.LockLevel = TIM_LOCKLEVEL_OFF;
  sBreakDeadTimeConfig.DeadTime = 10;
  sBreakDeadTimeConfig.BreakState = TIM_BREAK_DISABLE;
  sBreakDeadTimeConfig.BreakPolarity = TIM_BREAKPOLARITY_HIGH;
  sBreakDeadTimeConfig.BreakFilter = 0;
  sBreakDeadTimeConfig.Break2State = TIM_BREAK2_DISABLE;
  sBreakDeadTimeConfig.Break2Polarity = TIM_BREAK2POLARITY_HIGH;
  sBreakDeadTimeConfig.Break2Filter = 0;
  sBreakDeadTimeConfig.AutomaticOutput = TIM_AUTOMATICOUTPUT_DISABLE;
  if (HAL_TIMEx_ConfigBreakDeadTime(&htim1, &sBreakDeadTimeConfig) != HAL_OK)
  {
    Error_Handler();
  }
  HAL_TIM_MspPostInit(&htim1);

}

/**
  * Enable DMA controller clock
  */
static void MX_DMA_Init(void)
{

  /* DMA controller clock enable */
  __HAL_RCC_DMA1_CLK_ENABLE();

}

/**
  * @brief GPIO Initialization Function
  * @param None
  * @retval None
  */
void MX_GPIO_Init(void)
{
  GPIO_InitTypeDef GPIO_InitStruct = {0};
  /* GPIO Ports Clock Enable */
  __HAL_RCC_GPIOB_CLK_ENABLE();
  __HAL_RCC_GPIOF_CLK_ENABLE();
  __HAL_RCC_GPIOE_CLK_ENABLE();
  __HAL_RCC_GPIOC_CLK_ENABLE();

  /*Configure GPIO pin Output Level */
  HAL_GPIO_WritePin(ISR1_GPIO_Port, ISR1_Pin, GPIO_PIN_RESET);

  /*Configure GPIO pin Output Level */
  HAL_GPIO_WritePin(ISR_GPIO_Port, ISR_Pin, GPIO_PIN_RESET);

  /*Configure GPIO pin : ISR1_Pin */
  GPIO_InitStruct.Pin = ISR1_Pin;
  GPIO_InitStruct.Mode = GPIO_MODE_OUTPUT_PP;
  GPIO_InitStruct.Pull = GPIO_NOPULL;
  GPIO_InitStruct.Speed = GPIO_SPEED_FREQ_LOW;
  HAL_GPIO_Init(ISR1_GPIO_Port, &GPIO_InitStruct);

  /*Configure GPIO pin : ISR_Pin */
  GPIO_InitStruct.Pin = ISR_Pin;
  GPIO_InitStruct.Mode = GPIO_MODE_OUTPUT_PP;
  GPIO_InitStruct.Pull = GPIO_NOPULL;
  GPIO_InitStruct.Speed = GPIO_SPEED_FREQ_LOW;
  HAL_GPIO_Init(ISR_GPIO_Port, &GPIO_InitStruct);

}

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


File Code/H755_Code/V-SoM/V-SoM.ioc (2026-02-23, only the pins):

Mcu.UserName=STM32H745ZITx
PA1.Signal=ETH_REF_CLK
PA2.Signal=ETH_MDIO
PA7.Signal=ETH_CRS_DV
PB0.Signal=ADCx_INP9
PB1.Signal=ADCx_INP5
PB11.GPIO_Label=ISR1
PB11.Signal=GPIO_Output
PB13.Signal=ETH_TXD1
PB14.GPIO_Label=LD3 [Red Led]
PB14.Signal=GPIO_Output
PC1.Signal=ETH_MDC
PC13.GPIO_Label=B1 [Blue PushButton]
PC13.Signal=GPIO_Input
PC4.Signal=ETH_RXD0
PC5.Signal=ETH_RXD1
PC6.Signal=HRTIM_CHA1
PC7.Signal=HRTIM_CHA2
PD10.GPIO_Label=USB_OTG_FS_PWR_EN
PD10.Signal=GPIO_Output
PD8.GPIO_Label=STLINK_RX
PD8.Signal=USART3_TX
PD9.GPIO_Label=STLINK_TX
PD9.Signal=USART3_RX
PE0.GPIO_Label=ISR
PE0.Signal=GPIO_Output
PE1.GPIO_Label=LD2 [Yellow Led]
PE1.Signal=GPIO_Output
PE2.GPIO_Label=LD1 [Green Led]
PE2.Signal=GPIO_Output
PE8.Signal=TIM1_CH1N
PE9.Signal=S_TIM1_CH1
PF11.Signal=ADC1_INP2
PG11.Signal=ETH_TX_EN
PG13.Signal=ETH_TXD0

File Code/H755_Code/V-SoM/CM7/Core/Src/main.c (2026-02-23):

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
/* Includes ------------------------------------------------------------------*/
#include "main.h"
#include "cmsis_os.h"
#include "lwip.h"

/* USER CODE BEGIN Includes */
/* ETH_CODE: add lwiperf, see comment in StartDefaultTask function */
#include "lwip/apps/lwiperf.h"
#include "lwip/udp.h"

/* USER CODE END Includes */

/* USER CODE BEGIN PD */
#ifndef HSEM_ID_0
#define HSEM_ID_0 (0U) /* HW semaphore 0*/
#endif
/* USER CODE END PD */


TIM_HandleTypeDef htim2;

/* Definitions for defaultTask */
osThreadId_t defaultTaskHandle;
const osThreadAttr_t defaultTask_attributes = {
  .name = "defaultTask",
  .stack_size = 512 * 4,
  .priority = (osPriority_t) osPriorityNormal,
};
/* USER CODE BEGIN PV */
#include "VScopeV2.h"
void VScope_Stream(void);
void my_rx_cb(void *arg, struct udp_pcb *pcb, struct pbuf *p, const ip_addr_t *addr, u16_t port);
extern VScope_t VScope;


/* USER CODE END PV */

void SystemClock_Config(void);
static void MPU_Config(void);
static void MX_GPIO_Init(void);
static void MX_DMA_Init(void);
static void MX_TIM2_Init(void);
void StartDefaultTask(void *argument);

/* USER CODE BEGIN PFP */
void HAL_HSEM_FreeCallback(uint32_t SemMask);
/* USER CODE END PFP */

/* USER CODE BEGIN 0 */
void HAL_HSEM_FreeCallback(uint32_t SemMask)
{
	SCB_InvalidateDCache_by_Addr((uint32_t*)VSCOPE_SHM_BASE, 1000);
	__DMB();
	for(int i=0; i<VSCOPE_WIDTH;i++)
		VScope.dereference[i]=VScope_common.Buffer[i];
	HSEM->C1IER=1;
}
/* USER CODE END 0 */

/**
  * @brief  The application entry point.
  * @retval int
  */
int main(void)
{

  /* MPU Configuration--------------------------------------------------------*/
  MPU_Config();

  /* Enable the CPU Cache */

  /* Enable I-Cache---------------------------------------------------------*/
  SCB_EnableICache();

  /* Enable D-Cache---------------------------------------------------------*/
  SCB_EnableDCache();

  /* MCU Configuration--------------------------------------------------------*/

  /* Reset of all peripherals, Initializes the Flash interface and the Systick. */
  HAL_Init();

  /* Configure the system clock */
  SystemClock_Config();
  /* Initialize all configured peripherals */
  MX_GPIO_Init();
  MX_DMA_Init();
  MX_TIM2_Init();
  /* USER CODE BEGIN 2 */
	/* ETH_CODE: fixed core synchronization
	 * Release M4 core after GPIO and peripherals init
	 * to avoid conflict.
	 */
	__HAL_RCC_HSEM_CLK_ENABLE();
	HAL_HSEM_FastTake(HSEM_ID_0);
	HAL_HSEM_Release(HSEM_ID_0,0);
  /* USER CODE END 2 */

  /* Init scheduler */
  osKernelInitialize();

  /* USER CODE BEGIN RTOS_MUTEX */
	/* add mutexes, ... */
  /* USER CODE END RTOS_MUTEX */

  /* USER CODE BEGIN RTOS_SEMAPHORES */
	/* add semaphores, ... */
  /* USER CODE END RTOS_SEMAPHORES */

  /* USER CODE BEGIN RTOS_QUEUES */
  for(int i=0; i<VSCOPE_WIDTH;i++)
	  VScope.buffer[i]=&VScope.dereference[i];

  TIM2->CR1|=TIM_CR1_CEN;
  TIM2->DIER|=TIM_DIER_UIE;

  /* USER CODE END RTOS_QUEUES */

  /* Create the thread(s) */
  /* creation of defaultTask */
  defaultTaskHandle = osThreadNew(StartDefaultTask, NULL, &defaultTask_attributes);

  /* USER CODE BEGIN RTOS_THREADS */
	/* add threads, ... */
  /* USER CODE END RTOS_THREADS */

  /* USER CODE BEGIN RTOS_EVENTS */
	/* add events, ... */
  /* USER CODE END RTOS_EVENTS */

  /* Start scheduler */
  osKernelStart();

  /* We should never get here as control is now taken by the scheduler */

  /* Infinite loop */
  /* USER CODE BEGIN WHILE */
	while (1)
	{
    /* USER CODE END WHILE */

    /* USER CODE BEGIN 3 */
	}
  /* USER CODE END 3 */
}

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
/* USER CODE BEGIN Header_StartDefaultTask */
/**
 * @brief  Function implementing the defaultTask thread.
 * @param  argument: Not used
 * @retval None
 */
/* USER CODE END Header_StartDefaultTask */
void StartDefaultTask(void *argument)
{
  /* init code for LWIP */
  MX_LWIP_Init();
  /* USER CODE BEGIN 5 */
  HSEM->C1IER=1;
  osDelay(10);

  VScope_Stream();

  /* USER CODE END 5 */
}

 /* MPU Configuration */

void MPU_Config(void)
{
  MPU_Region_InitTypeDef MPU_InitStruct = {0};

  /* Disables the MPU */
  HAL_MPU_Disable();

  /** Initializes and configures the Region and the memory to be protected
  */
  MPU_InitStruct.Enable = MPU_REGION_ENABLE;
  MPU_InitStruct.Number = MPU_REGION_NUMBER0;
  MPU_InitStruct.BaseAddress = 0x0;
  MPU_InitStruct.Size = MPU_REGION_SIZE_4GB;
  MPU_InitStruct.SubRegionDisable = 0x87;
  MPU_InitStruct.TypeExtField = MPU_TEX_LEVEL0;
  MPU_InitStruct.AccessPermission = MPU_REGION_NO_ACCESS;
  MPU_InitStruct.DisableExec = MPU_INSTRUCTION_ACCESS_DISABLE;
  MPU_InitStruct.IsShareable = MPU_ACCESS_SHAREABLE;
  MPU_InitStruct.IsCacheable = MPU_ACCESS_NOT_CACHEABLE;
  MPU_InitStruct.IsBufferable = MPU_ACCESS_NOT_BUFFERABLE;

  HAL_MPU_ConfigRegion(&MPU_InitStruct);

  /** Initializes and configures the Region and the memory to be protected
  */
  MPU_InitStruct.Number = MPU_REGION_NUMBER1;
  MPU_InitStruct.BaseAddress = 0x30020000;
  MPU_InitStruct.Size = MPU_REGION_SIZE_128KB;
  MPU_InitStruct.SubRegionDisable = 0x0;
  MPU_InitStruct.TypeExtField = MPU_TEX_LEVEL1;
  MPU_InitStruct.AccessPermission = MPU_REGION_FULL_ACCESS;
  MPU_InitStruct.IsShareable = MPU_ACCESS_NOT_SHAREABLE;

  HAL_MPU_ConfigRegion(&MPU_InitStruct);

  /** Initializes and configures the Region and the memory to be protected
  */
  MPU_InitStruct.Number = MPU_REGION_NUMBER2;
  MPU_InitStruct.BaseAddress = 0x30040000;
  MPU_InitStruct.Size = MPU_REGION_SIZE_512B;
  MPU_InitStruct.TypeExtField = MPU_TEX_LEVEL0;
  MPU_InitStruct.IsShareable = MPU_ACCESS_SHAREABLE;
  MPU_InitStruct.IsBufferable = MPU_ACCESS_BUFFERABLE;

  HAL_MPU_ConfigRegion(&MPU_InitStruct);
  /* Enables the MPU */
  HAL_MPU_Enable(MPU_PRIVILEGED_DEFAULT);

}

/**
  * @brief  Period elapsed callback in non blocking mode
  * @note   This function is called  when TIM6 interrupt took place, inside
  * HAL_TIM_IRQHandler(). It makes a direct call to HAL_IncTick() to increment
  * a global variable "uwTick" used as application time base.
  * @param  htim : TIM handle
  * @retval None
  */
void HAL_TIM_PeriodElapsedCallback(TIM_HandleTypeDef *htim)
{
  if (htim->Instance == TIM6)
  {
    HAL_IncTick();
  }
}

/**
  * @brief  This function is executed in case of error occurrence.
  * @retval None
  */
void Error_Handler(void)
{
  /* USER CODE BEGIN Error_Handler_Debug */
	/* User can add his own implementation to report the HAL error return state */
	__disable_irq();
	while (1)
	{
	}
  /* USER CODE END Error_Handler_Debug */
}
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

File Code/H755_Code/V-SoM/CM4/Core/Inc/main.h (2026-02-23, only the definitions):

#define EXTERN extern
#define ARR 40000
#define ISR1_Pin GPIO_PIN_11
#define ISR1_GPIO_Port GPIOB
#define ISR_Pin GPIO_PIN_0
#define ISR_GPIO_Port GPIOE

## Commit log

2026-02-24 Update README with SoM features and programming info
    Enhanced the description of the SoM capabilities and programming details, including clarifications on the Cortex®-M4 and Cortex®-M7 cores, and improved the explanation of the PCB features and compati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
2026-02-24 Removed Gitignore
    [VScope_0000.csv]

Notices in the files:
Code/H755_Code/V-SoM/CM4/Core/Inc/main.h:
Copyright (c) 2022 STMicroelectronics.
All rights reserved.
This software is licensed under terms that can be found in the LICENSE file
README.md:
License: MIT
